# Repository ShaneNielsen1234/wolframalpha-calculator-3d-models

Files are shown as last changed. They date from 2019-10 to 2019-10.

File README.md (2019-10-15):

# wolframalpha-calculator-3d-models

Attached is the 3d models for the wolfram alpha calculator project.
This is a calculator that shows full step-by-step instructions to solve complex math problems.

You can see it in action here: https://www.youtube.com/watch?v=qwb0BAe3mJg

The button holes are based off of the removable keypad from the TI-NSpire. NSPIRE

The removable keypad has a 30 pin header on the top wired in matrix that can easily be interface by a raspberry pi. Info on this is available in keypad_pinout.pdf.

The middle plate has a cutout that should fit a standard 3000mAh battery. There is also 4 feet to mount a Adafruit powerboost for a charging circuit.

The screen is an unknown TFT panel connected over analog.

# Pictures
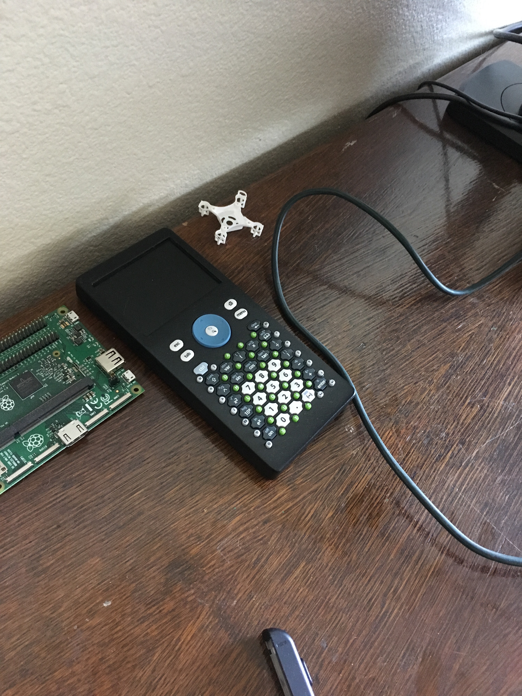
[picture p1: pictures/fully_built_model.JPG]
finished_model


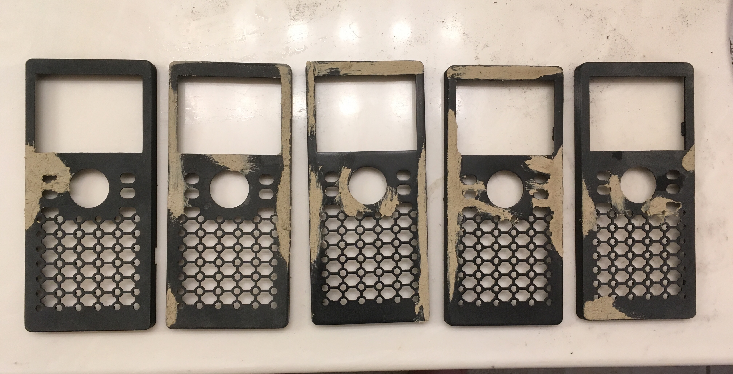
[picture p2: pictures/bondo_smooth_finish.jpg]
finishing_bondo


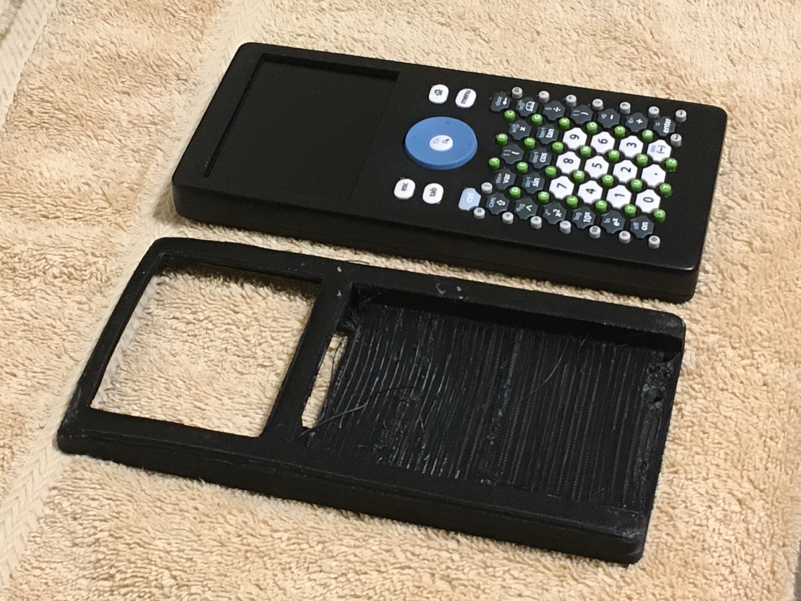
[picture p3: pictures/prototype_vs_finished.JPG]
prototype


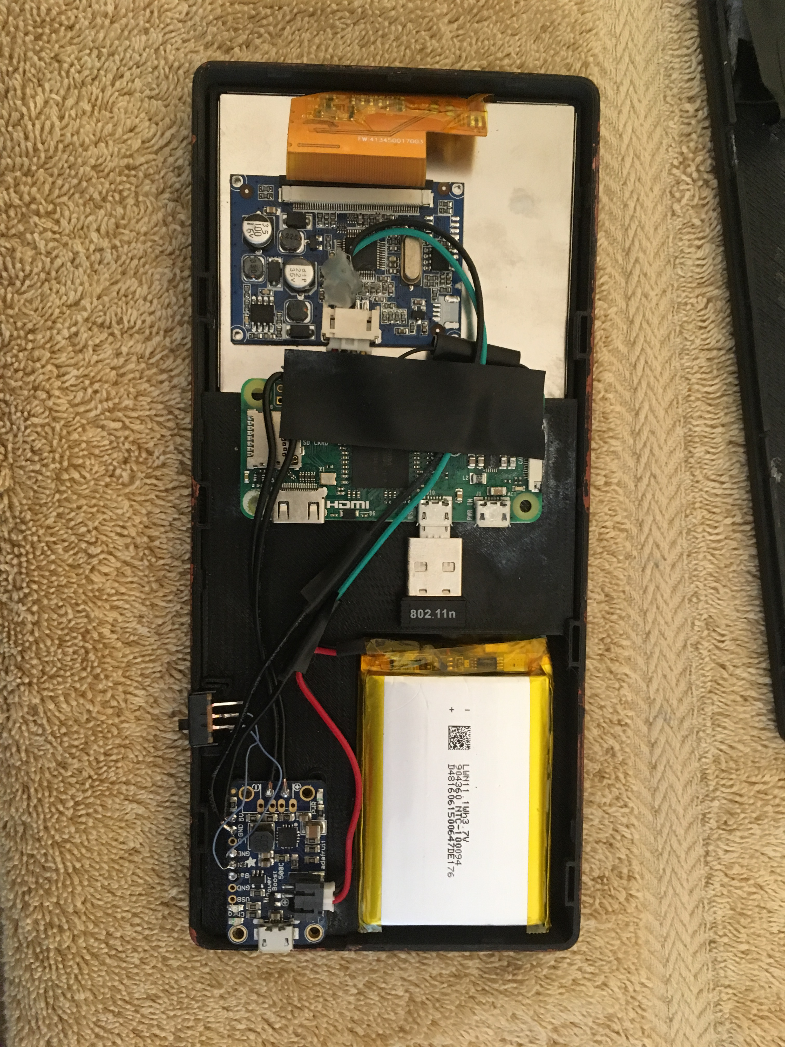
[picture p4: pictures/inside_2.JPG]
inside


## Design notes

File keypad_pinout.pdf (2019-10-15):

## Interfacing with the TI-Nspire Removable Keypad Brain Dump

This calculator has a removable keypad with these pins on the back. This board is super simple to work with and uses a simple matrix circuit.

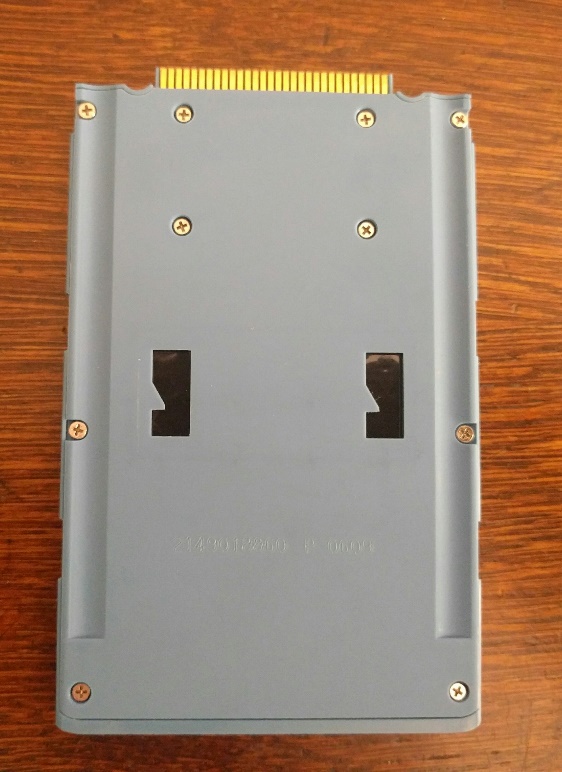
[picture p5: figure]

A very good article on how a matrix function is here: http://pcbheaven.com/wikipages/How_Key_Matrices_Works/

Getting it working

The keypad has 83 keys, and using a matrix layout means that 18 pins are the minimum amount required. (11pins x 8pins = 88 max keys) However, the keypad has 30 pins. So it is a fair assumption that many pins are left unused. Different keypads will have different pin requirements so it makes sense that this would happen. Before I connect it up I quickly took it apart to see if any of the pins are visibly unused.

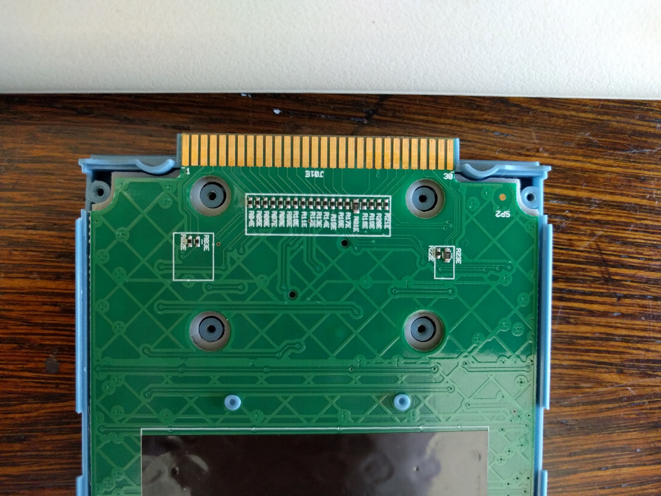
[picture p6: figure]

The pins are labeled 1-30. It looks like most of the pins have traces. I count 24 traces. By my earlier calculations we should have about 18 IO pins, and as per the website above 1 ground, and one VCC pin. So we have 4 pins that I am not sure the function of. This made me wonder if they are using a simple matrix or making it overly complex somehow. I never found the use of the 4 pins that have traces, but I can assume they proved to be functionally useless for my needs.

On the above website it mentions that the pins alternate column, row, column, row. With pins 1 being ground, and 2 being VCC. I wrote a really, really bad python program to detect the buttons:

import RPi.GPIO as GPIO
import time

GPIO.setmode(GPIO.BCM)

MATRIX = [ ["1A","1B","1C","1D","1E","1F","1G","1H","1I","1J","1k"], ["2A","2B","2C","2D","2E","2","2G","2H","2I","2J","2k"], ["3A","3B","3C","3D","3E","3F","3G","3H","3I","3J","3k"], ["4A","4B","4C","4D","4E","4F","4G","4H","4I","4J","4k"], ["5A","5B","5C","5D","5E","5F","5G","5H","5I","5J","5k"], ["6A","6B","6C","6D","6E","6F","6G","6H","6I","6J","6k"], ["7A","7B","7C","7D","7E","7F","7G","7H","7I","7J","7k"], ["8A","8B","8C","8D","8E","8F","8G","8H","8I","8J","8k"] ]

ROWRANGE = 8
COLRANGE = 11

ROW = [17,27,23,9,8,7,12,19] #19 is row not col (one of the 3) COL = [16,26,20,22,18,25,24,6,13,5,4] #16 is col not row

for j in range(COLRANGE):
GPIO.setup(COL[j], GPIO.OUT)
GPIO.output(COL[j], 1)

for i in range(ROWRANGE):
GPIO.setup(ROW[i], GPIO.IN, pull_up_down = GPIO.PUD_UP)

try:
while(True):
for j in range(COLRANGE):
GPIO.output(COL[j],0)

for i in range(ROWRANGE):
if GPIO.input(ROW[i]) == 0:
print MATRIX[i][j]
time.sleep(0.2)
while(GPIO.input(ROW[i]) == 0): pass

GPIO.output(COL[j],1)
except KeyboardInterrupt:
GPIO.cleanup()

The code works by scanning/applying voltage to each row, while checking each column for a change in voltage. If a column goes high while a row has power going through it than we have the coordinates for the button pressed. I tried using wire clips to test the keyboard, but the pins were a little too small for that. I ended up soldering 30 awg wire to each pin because I could not find a pin header that had the correct widths.

The col, row, col, row pattern randomly stops after the 8 cols/rows. We are looking for the pinout of an 11*8 matrix.

So it would make sense to have it be col, row, col, row, row, row… right? After some trial and error the last 3 rows are on pins 23, 25, and 26.

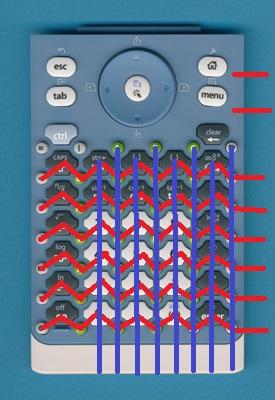
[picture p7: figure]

Linux Driver

To be added

### 83 Pin Keypad Pinout

COL = column pin for matrix ROW = row pin for matrix
DC = don’t know/care pin
1 | GND
2 | VCC
3 | COL
4 | ROW
5 | COL
6 | ROW
7 | COL
8 | ROW
9 | COL
10 | ROW
11 | COL
12 | ROW
13 | COL
14 | ROW
15 | COL
16 | ROW
17 | COL
18 | ROW
19 | DC
20 | DC
21 | DC
22 | DC
23 | ROW
24 | DC
25 | ROW
26 | ROW
27 | DC
28 | DC
29 | DC
30 | DC

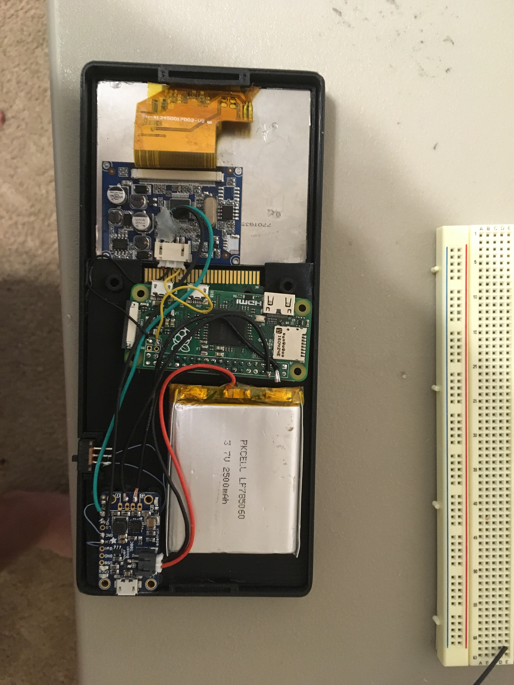
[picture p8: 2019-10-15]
pictures/inside_1.JPG

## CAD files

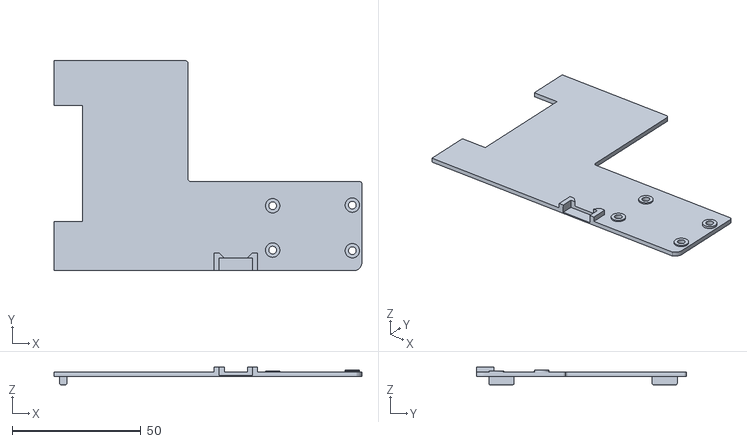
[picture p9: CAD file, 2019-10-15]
stl/front.stl
119.8 x 81.6 x 6.87

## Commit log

2019-10-14 Added photos of printed models
2019-10-14 Update README to include pictures of printed models
2019-10-15 Added STL and Autodesk models, updated README, added pictures
    [back.stl, front.stl, middle.stl]
